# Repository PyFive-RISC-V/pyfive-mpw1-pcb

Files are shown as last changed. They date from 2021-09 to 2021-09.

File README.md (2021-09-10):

# pyfive-mpw1-pcb
Breakout carrier for the MPW1 PyFive chip

PyFive specific pins
* mprj_io[11] = usb_dn
* mprj_io[12] = usb_dp
* mprj_io[13] = usb_pu
* mprj_io[14] = usb_sof
* mprj_io[15] = midi_tx
* mprj_io[16] = midi_rx
* mprj_io[17] = pcm_audio_1
* mprj_io[18] = pcm_audio_2
* mprj_io[19] = video_clk
* mprj_io[20] = video_de
* mprj_io[21] = video_hsync
* mprj_io[22] = video_vsync
* mprj_io[23] = video_r
* mprj_io[24] = video_g
* mprj_io[25] = video_b
* mprj_io[26] = video_i

Features
* Input current jumpers
* External clock input header
* 2.54" programming headers
* PCM => RC filter => op-amp => headphone jack
* Header for video output to DVI PMOD
* Buttons

Based on the [caravel_carrier](https://github.com/samlittlewood/caravel_carrier) design by Sam Littlewood.

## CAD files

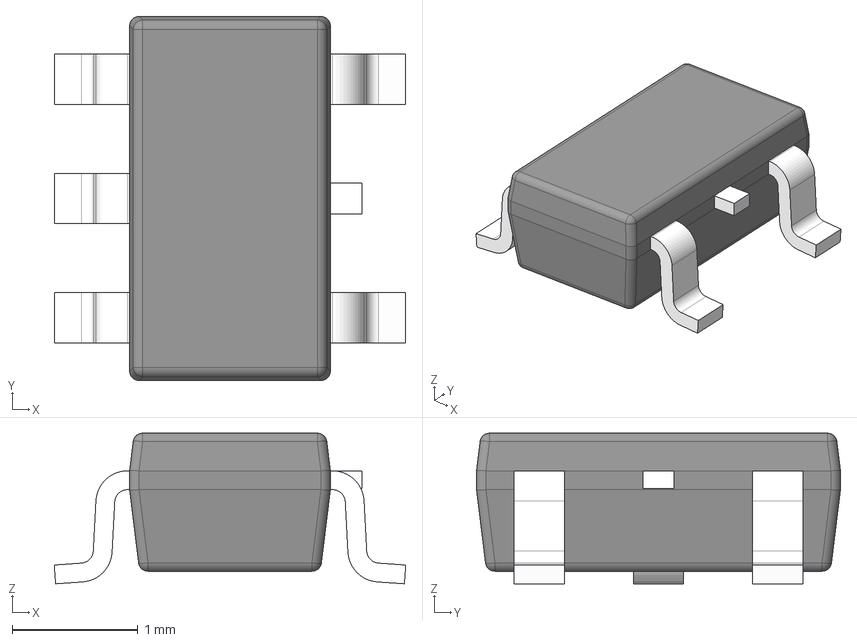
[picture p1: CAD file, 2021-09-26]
components/ESDS312DBVR/ESDS312DBVR.stp
2.80 x 2.90 x 1.20 mm
BODY-SOT
LEAD-SOT x 5
LEAD-DUMMY

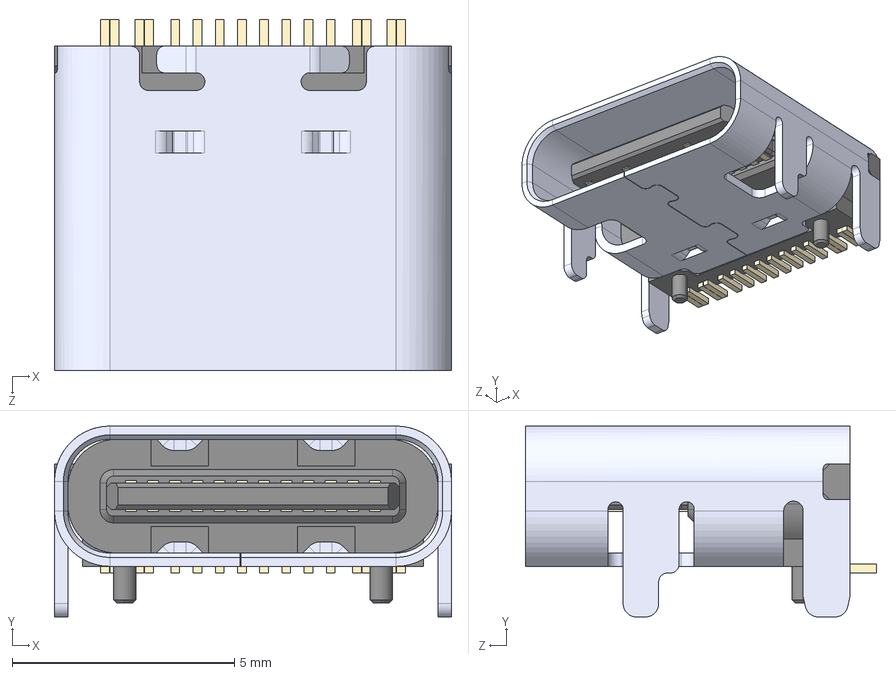
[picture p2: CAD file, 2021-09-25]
components/HRO_TYPE_C_31_M_12/TYPE-C-31-M-12.step
8.94 x 4.30 x 7.90 mm

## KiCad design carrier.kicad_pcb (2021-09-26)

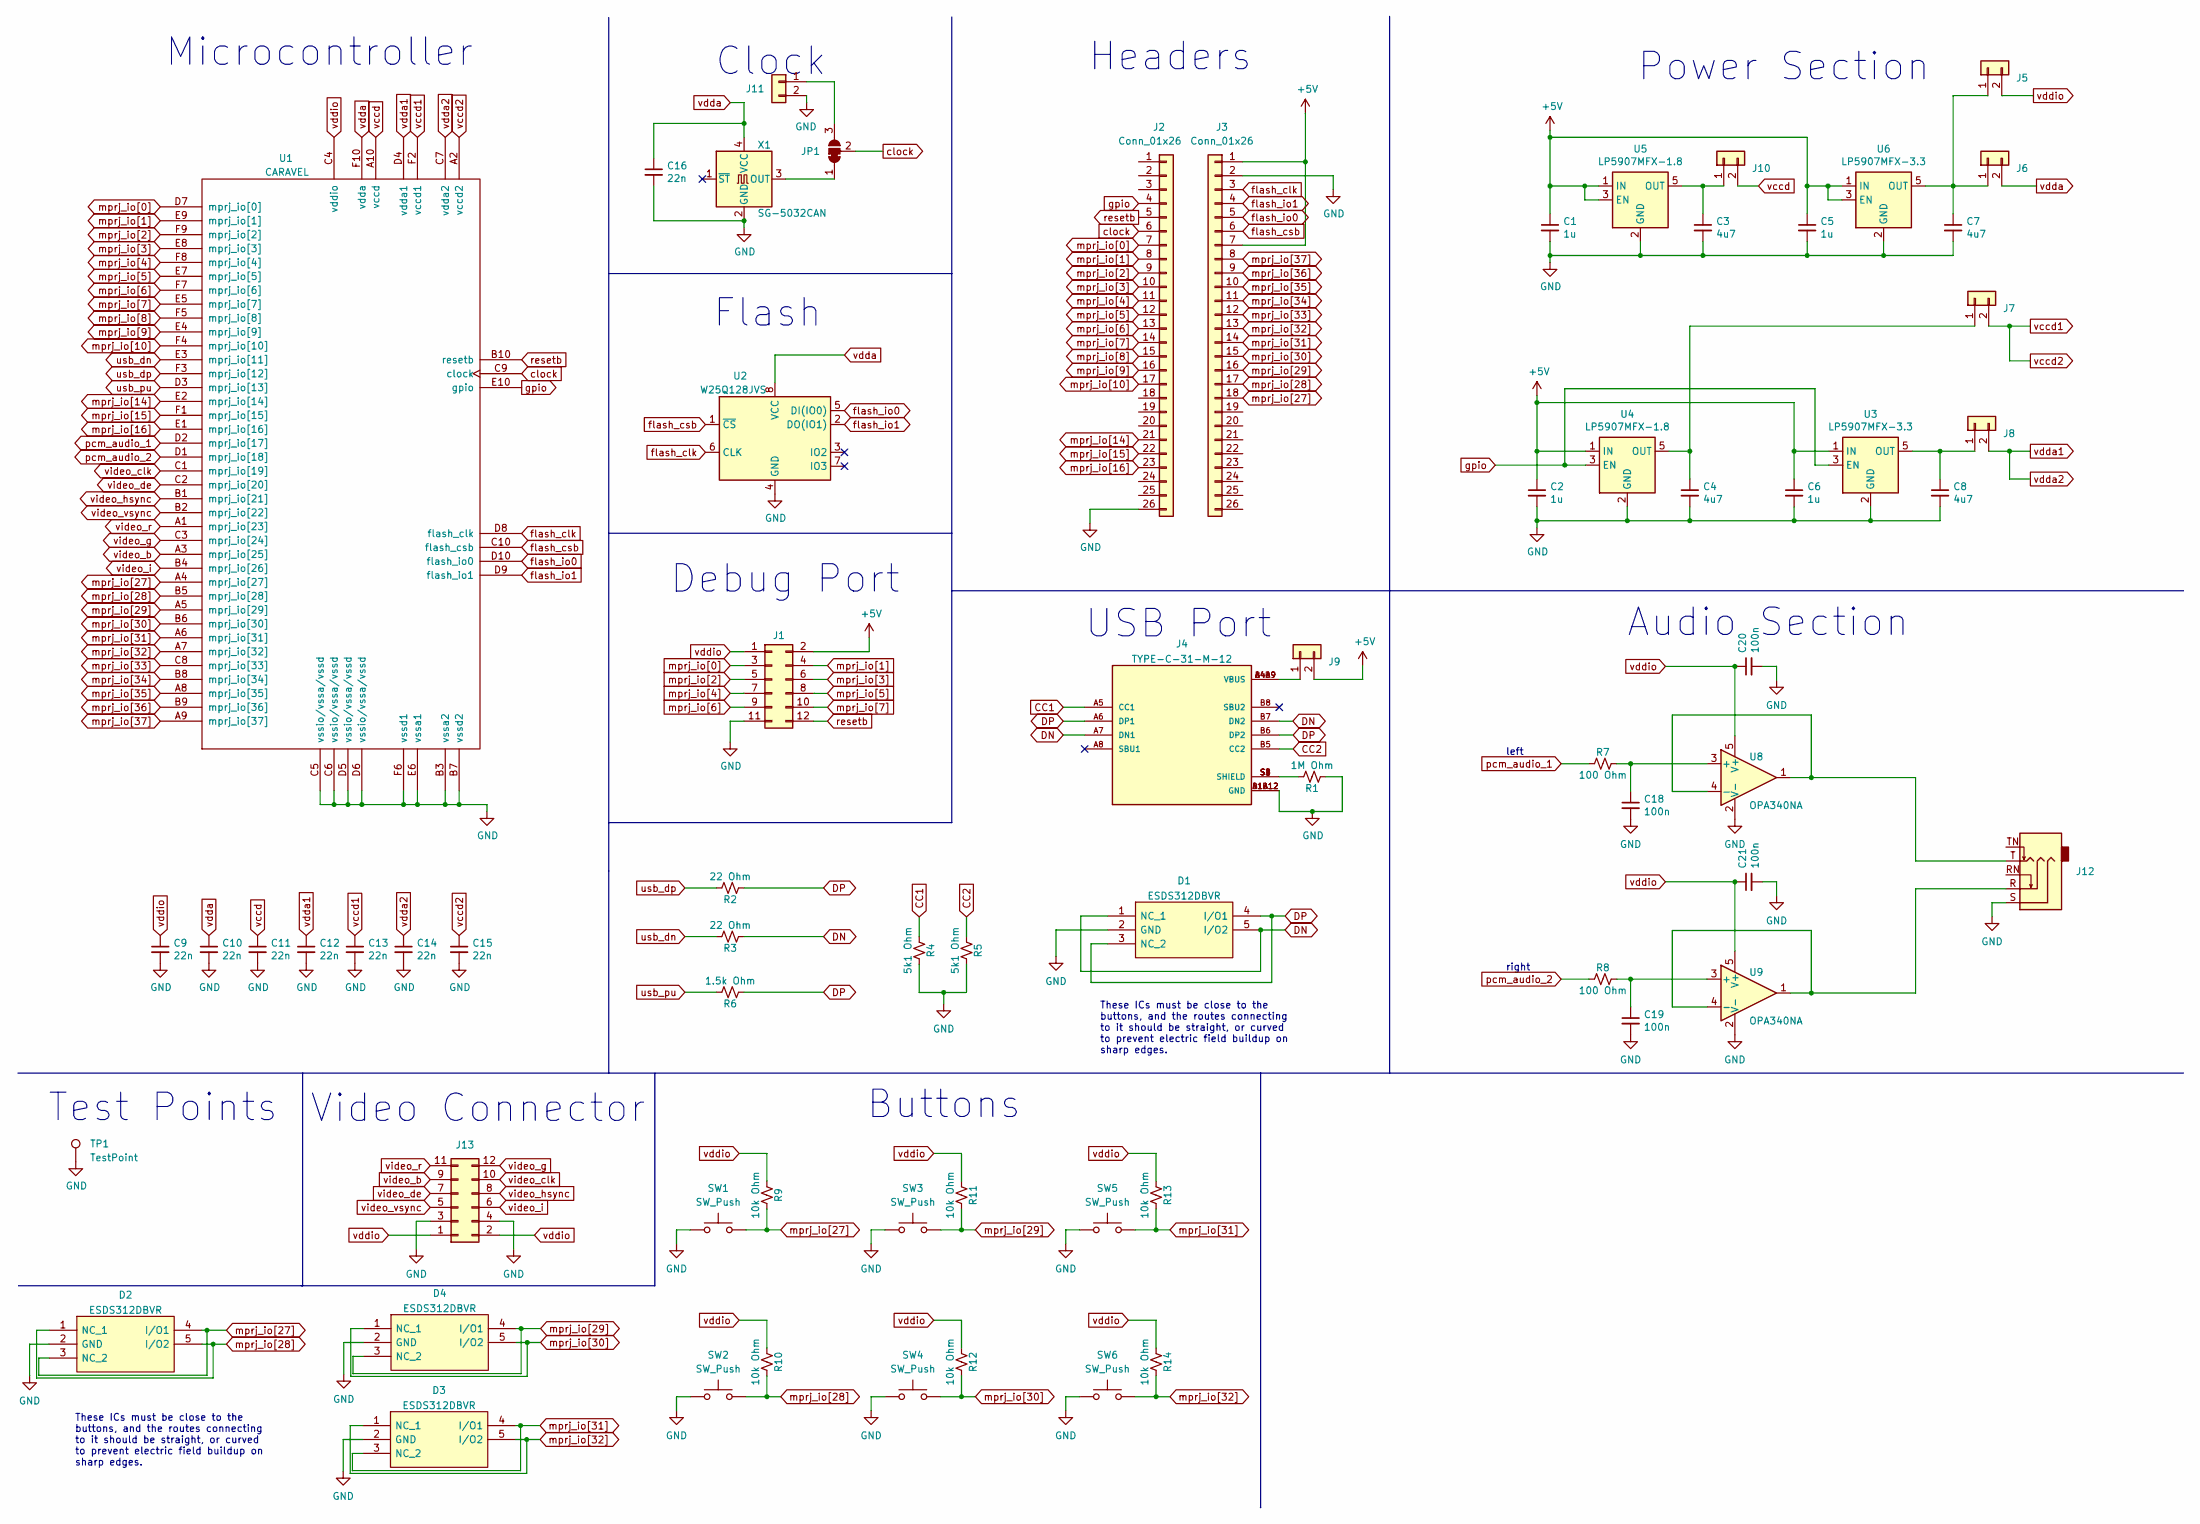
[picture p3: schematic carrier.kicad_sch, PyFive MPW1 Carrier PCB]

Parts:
C1, C2, C5, C6: 1u; C_0603_1608Metric
C3, C4, C7, C8: 4u7; C_0603_1608Metric
C9, C10, C11, C12, C13, C14, C15, C16: 22n; C_0402_1005Metric
C18, C19, C20, C21: 100n; C_0402_1005Metric
D1, D2, D3, D4: ESDS312DBVR; SOT-23-5; Manufacturer_Part_Number ESDS312DBVR; Mouser Part Number 595-ESDS312DBVR
J1: Conn_02x06_Odd_Even; PinHeader_2x06_P2.54mm_Vertical
J2, J3: Conn_01x26; PinHeader_1x26_P2.54mm_Vertical
J4: TYPE-C-31-M-12; HRO_TYPE-C-31-M-12; PARTREV A
J5, J6, J7, J8, J9, J10, J11: Conn_01x02; PinHeader_1x02_P2.54mm_Vertical
J12: AudioJack3_SwitchTR; Jack_3.5mm_CUI_SJ1-3535NG_Horizontal_CircularHoles
J13: Conn_02x06_Odd_Even; PinSocket_2x06_P2.54mm_Horizontal
JP1: SolderJumper_3_Bridged12; SolderJumper-3_P1.3mm_Bridged12_Pad1.0x1.5mm
R1: 1M Ohm; R_0402_1005Metric
R2, R3: 22 Ohm; R_0402_1005Metric
R4, R5: 5k1 Ohm; R_0402_1005Metric
R6: 1.5k Ohm; R_0402_1005Metric
R7, R8: 100 Ohm; R_0402_1005Metric
R9, R10, R11, R12, R13, R14: 10k Ohm; R_0402_1005Metric
SW1, SW2, SW3, SW4, SW5, SW6: SW_Push; SW_Push_1P1T_NO_CK_KMR2
TP1: TestPoint; TestPoint_Keystone_5000-5004_Miniature
U1: CARAVEL; WLCSP-60_P0.5mm
U2: W25Q128JVS; SOIC-8_5.23x5.23mm_P1.27mm
U3, U6: LP5907MFX-3.3; SOT-23-5
U4, U5: LP5907MFX-1.8; SOT-23-5
U8, U9: OPA340NA; SOT-23-5
X1: SG-5032CAN; Oscillator_SMD_SeikoEpson_SG8002LB-4Pin_5.0x3.2mm

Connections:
+5V: C1.1, C2.1, C5.1, C6.1, J1.2, J3.1, J3.7, J9.2, U3.1 (IN), U4.1 (IN), U5.1 (IN), U5.3 (EN), U6.1 (IN), U6.3 (EN)
CC1: J4.A5 (CC1), R4.2
CC2: J4.B5 (CC2), R5.2
DN: D1.1 (NC_1), D1.5 (I/O2), J4.A7 (DN1), J4.B7 (DN2), R3.2
DP: D1.3 (NC_2), D1.4 (I/O1), J4.A6 (DP1), J4.B6 (DP2), R2.2, R6.2
GND: C1.2, C2.2, C3.2, C4.2, C5.2, C6.2, C7.2, C8.2, C9.2, C10.2, C11.2, C12.2, C13.2, C14.2, C15.2, C16.2, C18.2, C19.2, C20.2, C21.2, D1.2 (GND), D2.2 (GND), D3.2 (GND), D4.2 (GND), J1.11, J2.26, J3.2, J4.A1B12 (GND), J4.B1A12 (GND), J11.2, J12.S, J13.3, J13.4, R1.2, R4.1, R5.1, SW1.1, SW2.1, SW3.1, SW4.1, SW5.1, SW6.1, TP1.1, U1.B3 (vssa2), U1.B7 (vssd2), U1.C5 (vssio/vssa/vssd), U1.C6 (vssio/vssa/vssd), U1.D5 (vssio/vssa/vssd), U1.D6 (vssio/vssa/vssd), U1.E6 (vssa1), U1.F6 (vssd1), U2.4 (GND), U3.2 (GND), U4.2 (GND), U5.2 (GND), U6.2 (GND), U8.2 (V-), U9.2 (V-), X1.2 (GND)
unnamed: C3.1, J10.1, U5.5 (OUT)
unnamed: C4.1, J7.1, U4.5 (OUT)
unnamed: C7.1, J5.1, J6.1, U6.5 (OUT)
unnamed: C8.1, J8.1, U3.5 (OUT)
unnamed: C18.1, R7.1, U8.3 (+)
unnamed: C19.1, R8.1, U9.3 (+)
unnamed: J4.A4B9 (VBUS), J4.B4A9 (VBUS), J9.1
unnamed: J4.S1 (SHIELD), J4.S2 (SHIELD), J4.S3 (SHIELD), J4.S4 (SHIELD), R1.1
unnamed: J11.1, JP1.3 (B)
unnamed: J12.R, U9.1, U9.4 (-)
unnamed: J12.T, U8.1, U8.4 (-)
unnamed: JP1.1 (A), X1.3 (OUT)
clock: J2.6, JP1.2 (C), U1.C9 (clock)
flash_clk: J3.3, U1.D8 (flash_clk), U2.6 (CLK)
flash_csb: J3.6, U1.C10 (flash_csb), U2.1 (~CS)
flash_io0: J3.5, U1.D10 (flash_io0), U2.5 (DI(IO0))
flash_io1: J3.4, U1.D9 (flash_io1), U2.2 (DO(IO1))
gpio: J2.4, U1.E10 (gpio), U3.3 (EN), U4.3 (EN)
mprj_io[0]: J1.3, J2.7, U1.D7 (mprj_io[0])
mprj_io[1]: J1.4, J2.8, U1.E9 (mprj_io[1])
mprj_io[2]: J1.5, J2.9, U1.F9 (mprj_io[2])
mprj_io[3]: J1.6, J2.10, U1.E8 (mprj_io[3])
mprj_io[4]: J1.7, J2.11, U1.F8 (mprj_io[4])
mprj_io[5]: J1.8, J2.12, U1.E7 (mprj_io[5])
mprj_io[6]: J1.9, J2.13, U1.F7 (mprj_io[6])
mprj_io[7]: J1.10, J2.14, U1.E5 (mprj_io[7])
mprj_io[8]: J2.15, U1.F5 (mprj_io[8])
mprj_io[9]: J2.16, U1.E4 (mprj_io[9])
mprj_io[10]: J2.17, U1.F4 (mprj_io[10])
mprj_io[14]: J2.21, U1.E2 (mprj_io[14])
mprj_io[15]: J2.22, U1.F1 (mprj_io[15])
mprj_io[16]: J2.23, U1.E1 (mprj_io[16])
mprj_io[27]: D2.3 (NC_2), D2.4 (I/O1), J3.18, R9.1, SW1.2, U1.A4 (mprj_io[27])
mprj_io[28]: D2.1 (NC_1), D2.5 (I/O2), J3.17, R10.1, SW2.2, U1.B5 (mprj_io[28])
mprj_io[29]: D4.3 (NC_2), D4.4 (I/O1), J3.16, R11.1, SW3.2, U1.A5 (mprj_io[29])
mprj_io[30]: D4.1 (NC_1), D4.5 (I/O2), J3.15, R12.1, SW4.2, U1.B6 (mprj_io[30])
mprj_io[31]: D3.3 (NC_2), D3.4 (I/O1), J3.14, R13.1, SW5.2, U1.A6 (mprj_io[31])
mprj_io[32]: D3.1 (NC_1), D3.5 (I/O2), J3.13, R14.1, SW6.2, U1.A7 (mprj_io[32])
mprj_io[33]: J3.12, U1.C8 (mprj_io[33])
mprj_io[34]: J3.11, U1.B8 (mprj_io[34])
mprj_io[35]: J3.10, U1.A8 (mprj_io[35])
mprj_io[36]: J3.9, U1.B9 (mprj_io[36])
mprj_io[37]: J3.8, U1.A9 (mprj_io[37])
pcm_audio_1: R7.2, U1.D2 (mprj_io[17])
pcm_audio_2: R8.2, U1.D1 (mprj_io[18])
resetb: J1.12, J2.5, U1.B10 (resetb)
usb_dn: R3.1, U1.E3 (mprj_io[11])
usb_dp: R2.1, U1.F3 (mprj_io[12])
usb_pu: R6.1, U1.D3 (mprj_io[13])
vccd: C11.1, J10.2, U1.A10 (vccd)
vccd1: C13.1, C15.1, J7.2, U1.A2 (vccd2), U1.F2 (vccd1)
vdda: C10.1, C16.1, J6.2, U1.F10 (vdda), U2.8 (VCC), X1.4 (VCC)
vdda1: C12.1, C14.1, J8.2, U1.C7 (vdda2), U1.D4 (vdda1)
vddio: C9.1, C20.1, C21.1, J1.1, J5.2, J13.1, J13.2, R9.2, R10.2, R11.2, R12.2, R13.2, R14.2, U1.C4 (vddio), U8.5 (V+), U9.5 (V+)
video_b: J13.9, U1.A3 (mprj_io[25])
video_clk: J13.10, U1.C1 (mprj_io[19])
video_de: J13.7, U1.C2 (mprj_io[20])
video_g: J13.12, U1.C3 (mprj_io[24])
video_hsync: J13.8, U1.B1 (mprj_io[21])
video_i: J13.6, U1.B4 (mprj_io[26])
video_r: J13.11, U1.A1 (mprj_io[23])
video_vsync: J13.5, U1.B2 (mprj_io[22])

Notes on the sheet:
Test Points
These ICs must be close to the buttons, and the routes connecting to it should be straight, or curved to prevent electric field buildup on sharp edges.
Microcontroller
Video Connector
Debug Port
Flash
Clock
Buttons
USB Port
Headers
left
right
Audio Section
Power Section

Board: 4 copper layers, 68 parts (0 on the bottom side), 68 nets, no tracks yet.

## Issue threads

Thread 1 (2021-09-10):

Add current input jumpers

mwelling, 2021-09-10:
Remove the solder bridges and add a 2 pin header for measuring the current of each rail.

Use standard 2.54" header and add shunt to BOM.

mwelling, 2021-09-25:
Done!

Closed 2021-09-25.

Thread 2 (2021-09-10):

Add option for external clock via header

mwelling, 2021-09-10:
Use solder bridge or zero ohm population option to allow an optional 2 pin header for applying an external clock.

mwelling, 2021-09-25:
Done!

Closed 2021-09-25.

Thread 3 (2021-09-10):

Switch programming header to 2.54mm through hole

mwelling, 2021-09-10:
Header will contain the caravel management pins currently broken out to J1 which is 1.27mm SMT.

mwelling, 2021-09-25:
Done.

Closed 2021-09-25.

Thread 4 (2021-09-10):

Add PCM audio circuitry

mwelling, 2021-09-10:
Add a simple RC filter and op amp follower to the PCM outputs.

Bring the conditioned output to a stereo headphone jack.

mwelling, 2021-09-26:
Done!

Closed 2021-09-26.

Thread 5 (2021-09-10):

Add headers to break out video to 1bitsquared DVI PMOD

mwelling, 2021-09-10:
We only have 4bit video so we can probably use that variant.

https://1bitsquared.com/products/pmod-digital-video-interface
https://github.com/icebreaker-fpga/icebreaker-pmod/blob/master/dvi-4bit/v1.1b/dvi-4bit-sch.pdf

mwelling, 2021-09-26:
Added a header that should work but may want to change to pin numbering convention to match PMOD to avoid confusion.

Should double check the pinout as well.

Closed 2021-09-26.

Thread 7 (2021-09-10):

Add USB connector

mwelling, 2021-09-10:
Add USB connector.

USB-C connectors seems to be all the rage these days so lets go with it.

VedantParanjape, 2021-09-22:
Self assigned this issue

Closed 2021-09-25.

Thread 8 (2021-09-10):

Switch on-board oscillator

mwelling, 2021-09-10:
Switch the on-board oscillator to something best fits the design.

USB is the main feature so I would imagine 12MHz would be good.

mwelling, 2021-09-25:
Looks like there is a 12Mhz SG-5032CAN in stock at mouser:
https://www.mouser.com/ProductDetail/Epson-Timing/SG5032CAN-12000000M-TJGA3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

Closed 2021-09-26.

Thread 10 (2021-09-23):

ASIC footprint is wrong

mwelling, 2021-09-23:
The footprint of the ASIC needs to be changed. It is mirrored according to Tim Edwards.

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

mwelling, 2021-09-23:
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

mwelling, 2021-09-25:
Fixed!

Closed 2021-09-25.

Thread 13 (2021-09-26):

Update ESD clamp footprint

mwelling, 2021-09-26:
Make sure that it has a courtyard and otherwise aligns with the KiCAD standard silk screen etc.

mwelling, 2021-09-26:
Perhaps switch to the following for nicer route
https://www.mouser.in/ProductDetail/Texas-Instruments/ESDS312DBVR?qs=byeeYqUIh0PGNqB7QuJpTA%3D%3D

Closed 2021-09-26.

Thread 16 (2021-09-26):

Review and update DVI PMOD connector as needed

mwelling, 2021-09-26:
The KiCAD library didn't have the PCB footprint with the appropriate pin out for PMOD.

Review the connections vs the DVI PMOD and update as necessary.

Even if it is just the pin numbering convention still update it so that it matches the PMOD.

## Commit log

2021-09-10 Manually fork carvel_carrier design
    Pulls in the caravel_carrier design from Sam Littlewood (mentioned in schematic header)
    Brings design to KiCad 5.99 format.
    Removes random silkscreen.
    [carrier.kicad_pcb, carrier.kicad_sch]
2021-09-25 Cleanup schematics by dividing it into relevant sections
    [carrier.kicad_sch]
2021-09-25 Added schematics for USB Section
    [TPD2E001DRSR.step, TYPE-C-31-M-12.step, carrier.kicad_sch]
2021-09-25 Switch to 2.54mm header for programming
    Also imports changes from schematic to PCB.
    [carrier.kicad_pcb, carrier.kicad_sch]
2021-09-25 Update caravel ASIC footprint
    It was mirrored about the Y-axis.
    Thanks to Tim Edwards and Matt Venn for flagging this issue.
    [carrier.kicad_pcb]
2021-09-25 Add current measurement jumpers
    Removes solder bridges and adds jumpers for each power rail to measure current.
    [carrier.kicad_pcb, carrier.kicad_sch]
2021-09-25 Add provision for external clk on pin header
    Uses a solder jumper to select oscillator by default.
    [carrier.kicad_pcb, carrier.kicad_sch]
2021-09-26 Add audio circuitry
    Adds headphone output for the PCM audio output
    [carrier.kicad_pcb, carrier.kicad_sch]
2021-09-26 Add GND hook test point
    Might want to add more test points for various things.
    [carrier.kicad_pcb, carrier.kicad_sch]
2021-09-26 Add video connector
    May want to use PMOD specific connector numbering to avoid confusion.
    [carrier.kicad_pcb, carrier.kicad_sch]
2021-09-26 Add some buttons
    May want to consider adding ESD clamps to buttons.
    [carrier.kicad_pcb, carrier.kicad_sch]
2021-09-26 schematics: Replaced TPD2E001DRSR with ESDS312DBVR
    ESDS312DBVR has a better footprint which makes routing around it easier.
    Also, it is much cheaper than the earlier chip used.
    Fixes #13
    [ESDS312DBVR.stp, TPD2E001DRSR.step, carrier.kicad_sch]
2021-09-26 schematics: Changed the colour of ESDS312DBVR to match other footprints
    [carrier.kicad_sch]
2021-09-26 schematics: Cleanup schematics
    * Divide the subcircuits using grid
    * Annotate symbol name to ESDS312DBVR
    [carrier.kicad_sch]
2021-09-26 schematics: Added ESD Protection for buttons
    Add ESDS312DBVR chip to the input GPIOs connected to the buttons.
    [carrier.kicad_sch]
2021-09-26 Switch KiCAD standard SOT-23-5 footprint
    No need to reinvent the wheel.
    [carrier.kicad_pcb, carrier.kicad_sch]
